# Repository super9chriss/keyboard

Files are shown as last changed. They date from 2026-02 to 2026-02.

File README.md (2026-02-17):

# custom keyboard
This is a split keyboard which can be aligned to work like a normal keyboard, it also has a removable numpad which conects to the main keyboard using pogo connectors. 
The keycaps are going to be 3d printed using these keycaps: https://www.printables.com/model/593307-low-profile-small-mx-keycaps-set/files


I wanted to make a split keyboard since my wrist hurt after typing for a long time, but im used to typing on a normal keyboard so i wanted to have this possiblity aswel,
i use a numpad for some programs so i also wanted to have that but since my desk is alway cluttered with stuff i wanted to have a keyboard which isnt too big so i made it removable.
## PCB and schematic
| **PCB Layout** | **Schematic** |
| :---: | :---: |
||
||
||
|| 
## BOM
|Description |quantity |price |link |
|---|---|---|---|
|switches |110 |25.99 + 4.72(shipping)|https://nl.aliexpress.com/item/1005010167220637.html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|
|Pico |2 |4.89 |https://nl.aliexpress.com/item/1005006839247100.html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 |
|pogo connector 5pin|2 |7.02 |https://nl.aliexpress.com/item/1005006839247100.html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 |
|diodes |110(need to order 200)|3.98 |https://nl.aliexpress.com/item/1005005574663623.html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 |
|PCB |1 |41.14 |https://cart.jlcpcb.com/shopcart/cart |
|LED |1 |0 |Self sourced |
| |total in euro: |87.74 |aliexpress coupon saves 4 euro so 83.74 |
| |in usd |100 | |

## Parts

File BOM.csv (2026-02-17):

Description | quantity | price | link
switches | 110 | 25.99 + 4.72(shipping) | https://nl.aliexpress.com/item/1005010167220637.html?mp=1
Pico | 2 | 4.89 | https://nl.aliexpress.com/item/1005006839247100.html?mp=1
pogo connector 5pin | 2 | 7.02 | https://nl.aliexpress.com/item/1005006839247100.html?mp=1
diodes | 110(need to order 200) | 3.98 | https://nl.aliexpress.com/item/1005005574663623.html?mp=1
PCB | 1 | 41.14 | https://cart.jlcpcb.com/shopcart/cart
LED | 1 | 0 | Self sourced
 | total in euro: | 87.74 | aliexpress coupon saves 4 euro so 83.74
 | in usd | 100

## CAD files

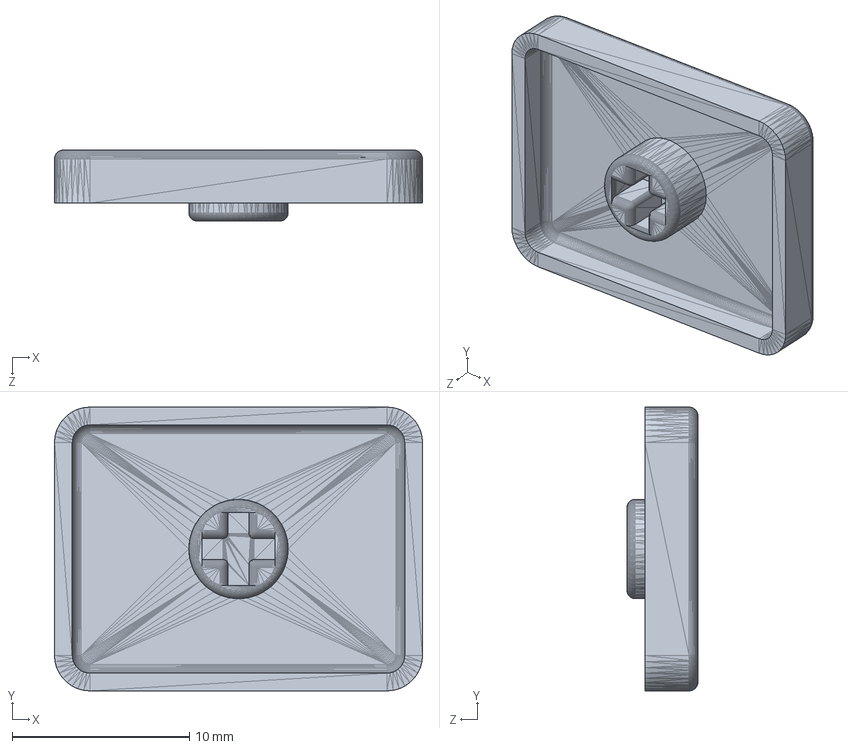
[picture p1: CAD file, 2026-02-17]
CAD/keycaps/1_25x.STEP
20.7 x 16.0 x 4.00 mm

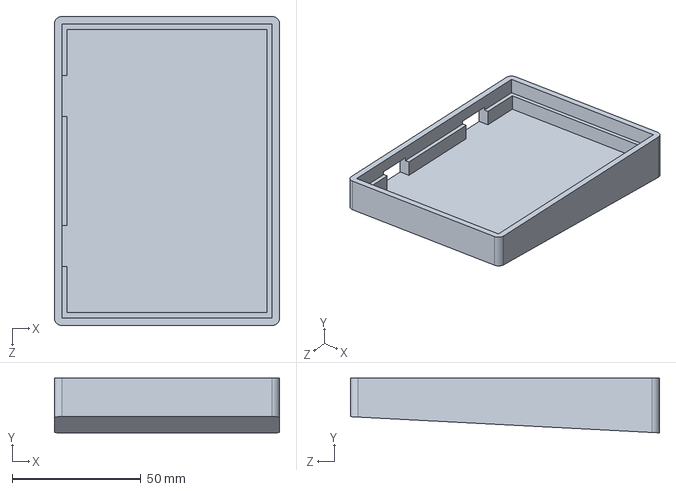
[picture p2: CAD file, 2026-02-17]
CAD/Numpad.STEP
87.7 x 21.3 x 120.2 mm

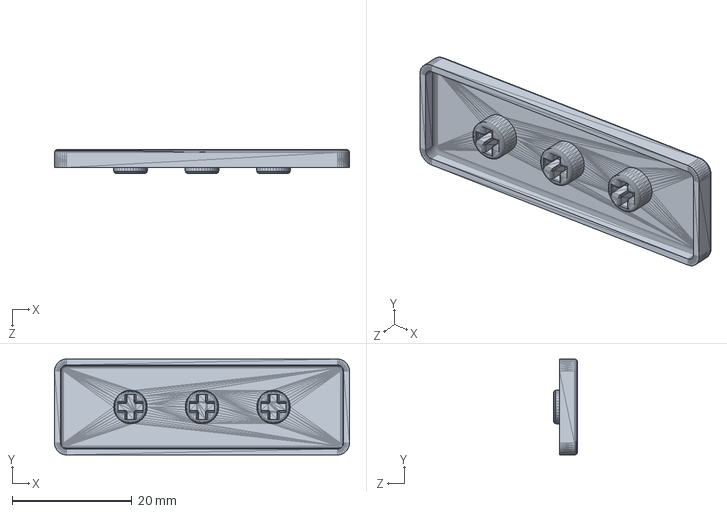
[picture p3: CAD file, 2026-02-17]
CAD/keycaps/2_75x.STEP
49.2 x 16.0 x 4.00 mm

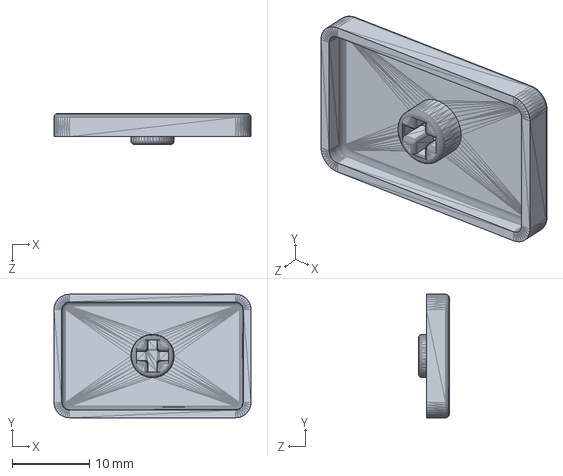
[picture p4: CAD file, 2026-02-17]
CAD/keycaps/1_5x.STEP
25.5 x 16.0 x 4.00 mm

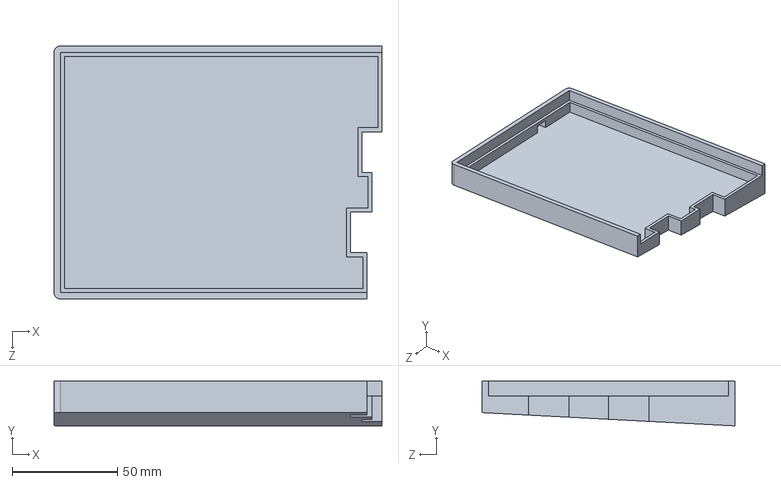
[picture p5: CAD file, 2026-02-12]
CAD/left side.SLDPRT
155.9 x 21.3 x 120.3 mm

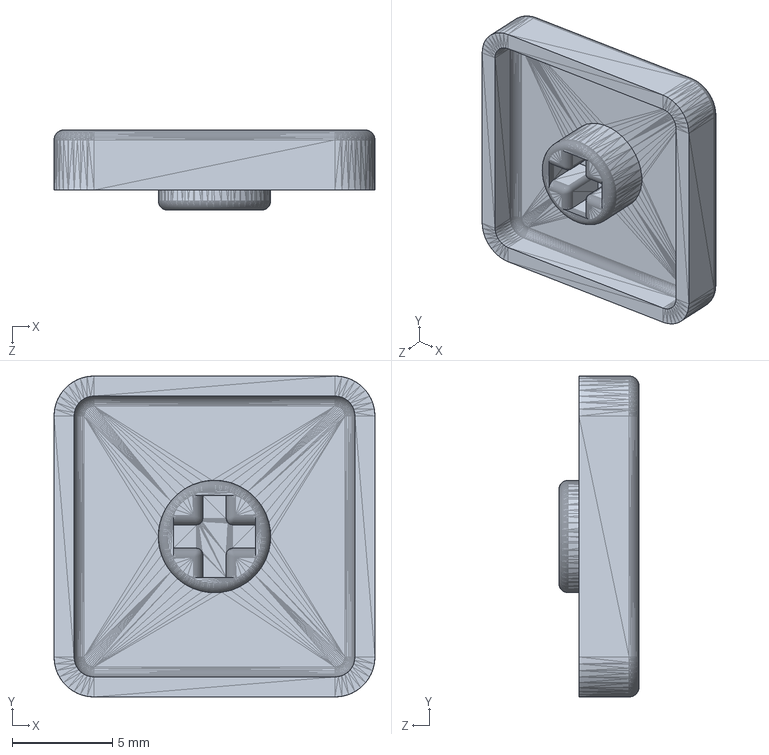
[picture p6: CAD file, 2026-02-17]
CAD/keycaps/1x.STEP
16.0 x 16.0 x 4.00 mm

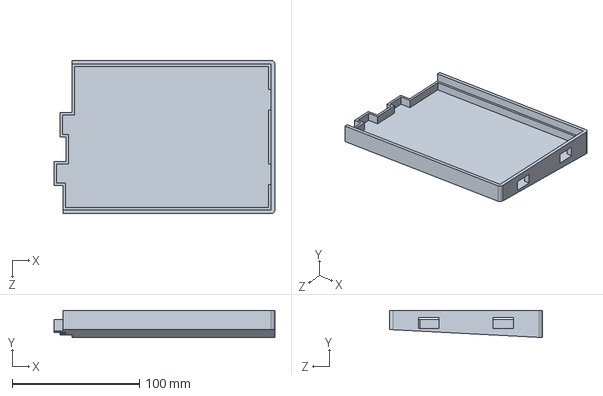
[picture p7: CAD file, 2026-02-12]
CAD/right half.SLDPRT
173.4 x 21.3 x 120.3 mm

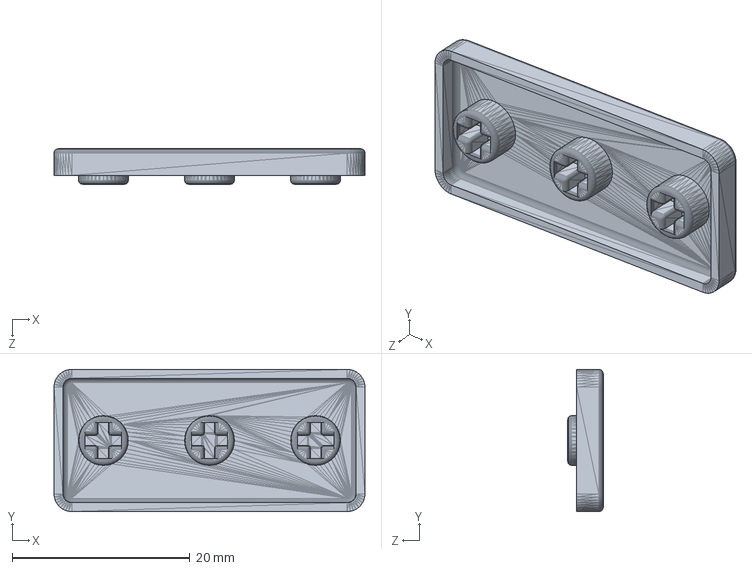
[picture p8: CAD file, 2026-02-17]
CAD/keycaps/2x.STEP
35.0 x 16.0 x 4.00 mm

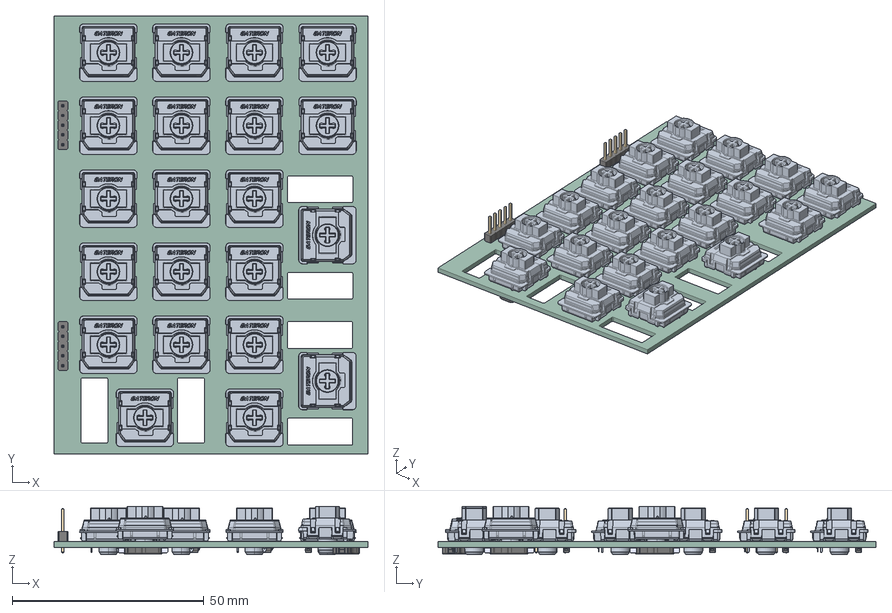
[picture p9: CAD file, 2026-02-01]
CAD/numpad PCB.step
81.8 x 114.2 x 12.6 mm
KS-33 Low Profile 2.0 KS33-20230109锛KS-33-Y31 3D寰锛 x 21
pin x 6
socket x 3
PinHeader_1x05_P2.54mm_Vertical x 2
D_SOD-123 x 21
numpad_PCB

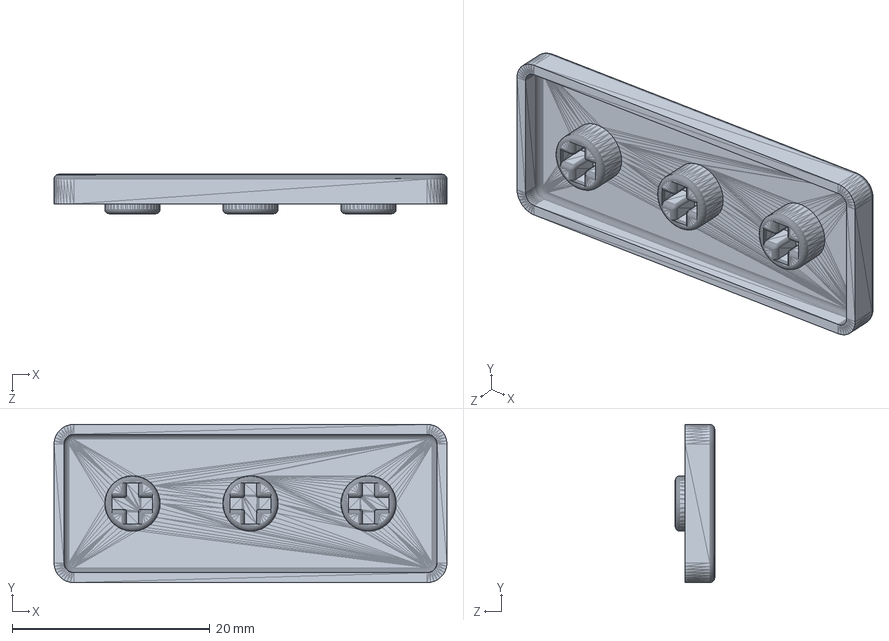
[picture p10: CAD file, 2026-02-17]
CAD/keycaps/2_25x.STEP
39.7 x 16.0 x 4.00 mm

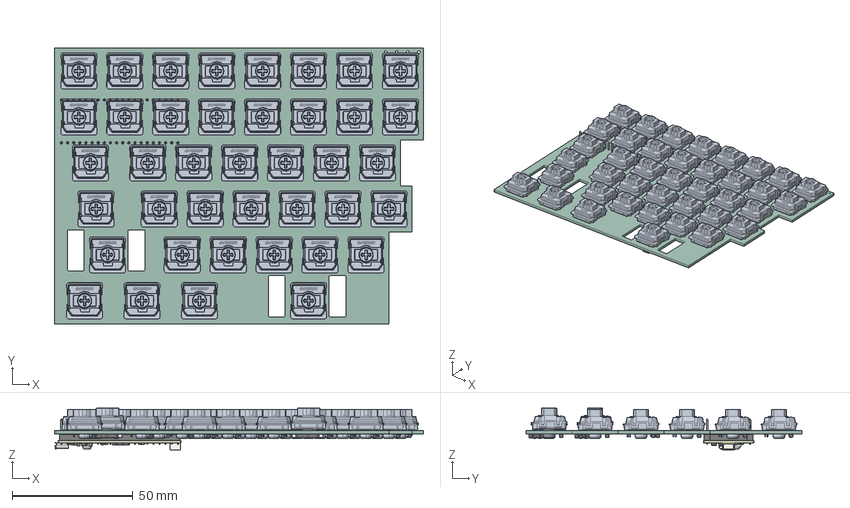
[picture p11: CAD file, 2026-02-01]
CAD/left PCB.step
153.0 x 114.3 x 17.3 mm
KS-33 Low Profile 2.0 KS33-20230109锛KS-33-Y31 3D寰锛 x 40
pin x 4
socket x 2
D_SOD-123 x 40
R_0805_2012Metric x 2
LED_SK6812MINI-E
RaspberryPi_Pico_H_Module_KiCad
RaspberryPi_Pico_Header_DIP-40_H2.54mm_KiCad
left_PCB

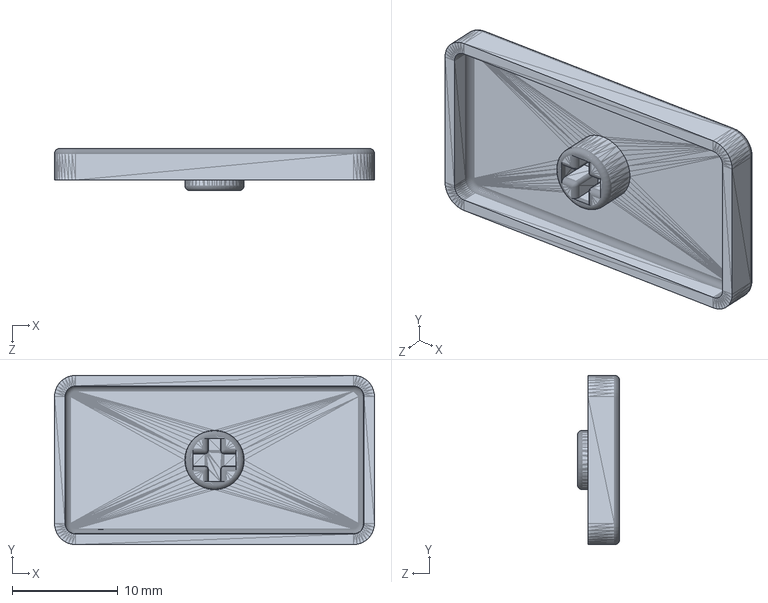
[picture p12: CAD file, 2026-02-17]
CAD/keycaps/1_75x.STEP
30.2 x 16.0 x 4.00 mm

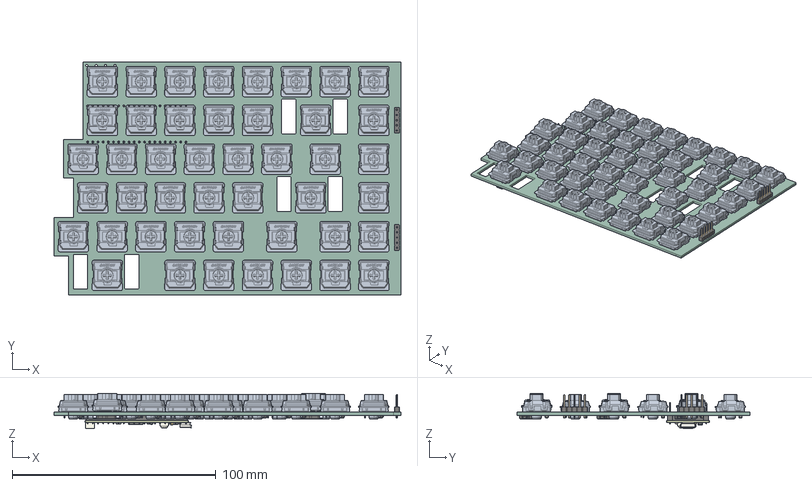
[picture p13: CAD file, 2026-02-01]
CAD/right PCB.step
170.5 x 114.3 x 17.3 mm
KS-33 Low Profile 2.0 KS33-20230109锛KS-33-Y31 3D寰锛 x 45
pin x 6
socket x 3
PinHeader_1x05_P2.54mm_Vertical x 2
D_SOD-123 x 45
RaspberryPi_Pico_H_Module_KiCad
RaspberryPi_Pico_Header_DIP-40_H2.54mm_KiCad
right_PCB

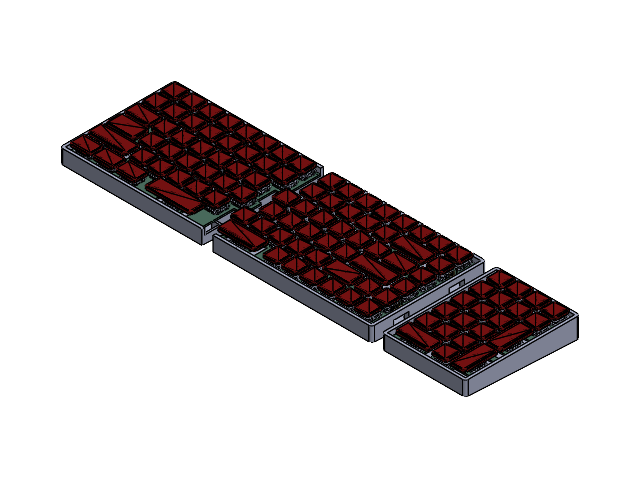
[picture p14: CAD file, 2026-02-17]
CAD/Assembely.SLDASM
left side
right half
Numpad
pin.step x 6
socket.step x 3
RaspberryPi_Pico_H_Module_KiCad.step
RaspberryPi_Pico_Header_DIP-40_H2.54mm_KiCad.step
KS-33 Low Profile 2.0 KS33-20230109______KS-33-Y31 3D____________.step x 45
PinHeader_1x05_P2.54mm_Vertical.step x 2
D_SOD-123.step x 45
right_PCB.step
pin_1.step x 4
socket_1.step x 2
RaspberryPi_Pico_H_Module_KiCad_1.step
RaspberryPi_Pico_Header_DIP-40_H2.54mm_KiCad_1.step
KS-33 Low Profile 2.0 KS33-20230109______KS-33-Y31 3D_____________1.step x 40
D_SOD-123_1.step x 40
R_0805_2012Metric.step x 2
LED_SK6812MINI-E.step
left_PCB.step
pin_2.step x 6
socket_2.step x 3
KS-33 Low Profile 2.0 KS33-20230109______KS-33-Y31 3D_____________2.step x 21
D_SOD-123_2.step x 21
numpad_PCB.step
keycap x 91
1_25x x 3
1_5x x 2
1_75x x 2
2x x 4
2_25x x 3
2_75x

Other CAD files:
CAD/right Case.STEP
CAD/left Case.STEP
CAD/Numpad.SLDPRT
CAD/keycaps/1_25x.SLDPRT
CAD/keycaps/1_5x.SLDPRT
CAD/keycaps/1_75x.SLDPRT
CAD/keycaps/1x.SLDPRT
CAD/keycaps/2_25x.SLDPRT
CAD/keycaps/2_75x.SLDPRT
CAD/keycaps/2x.SLDPRT

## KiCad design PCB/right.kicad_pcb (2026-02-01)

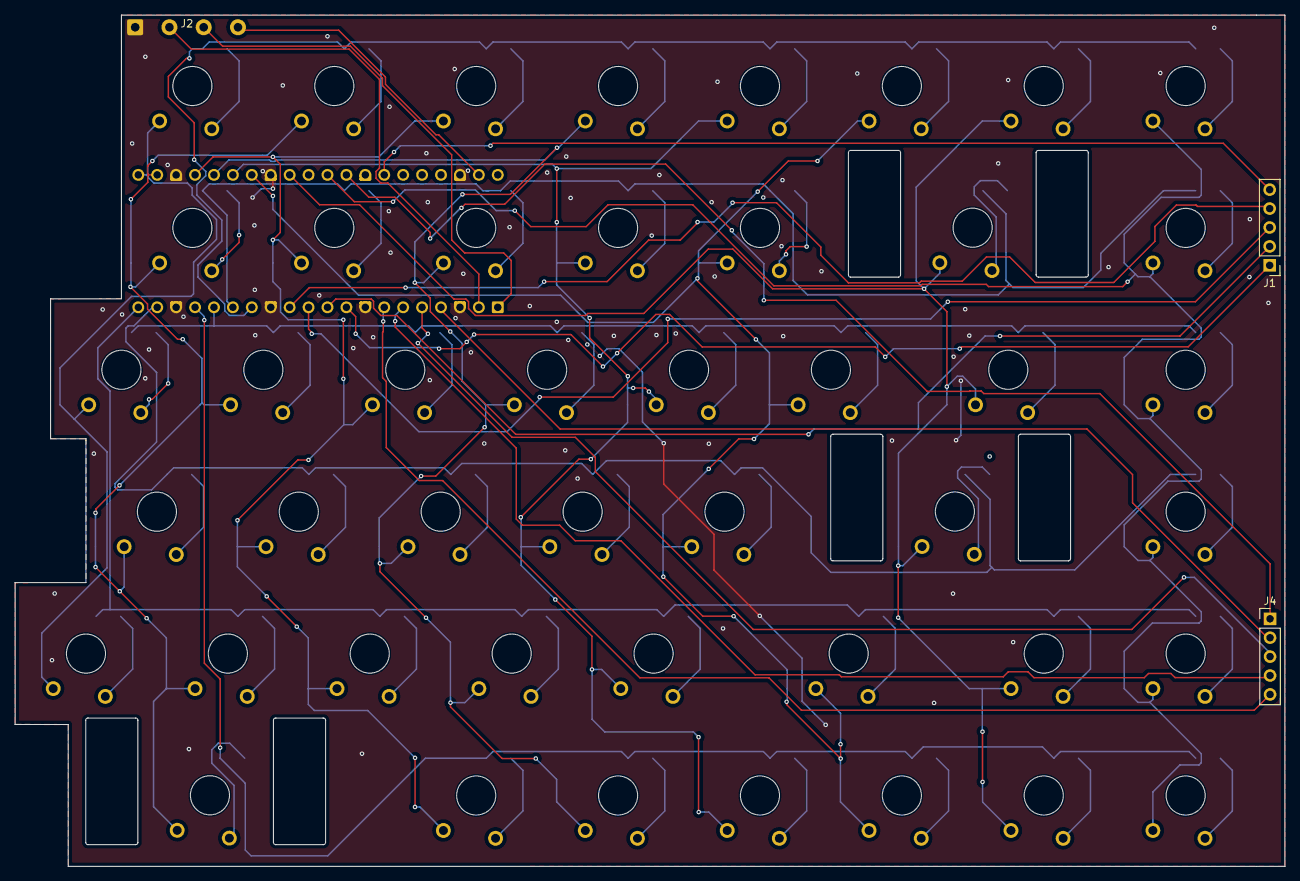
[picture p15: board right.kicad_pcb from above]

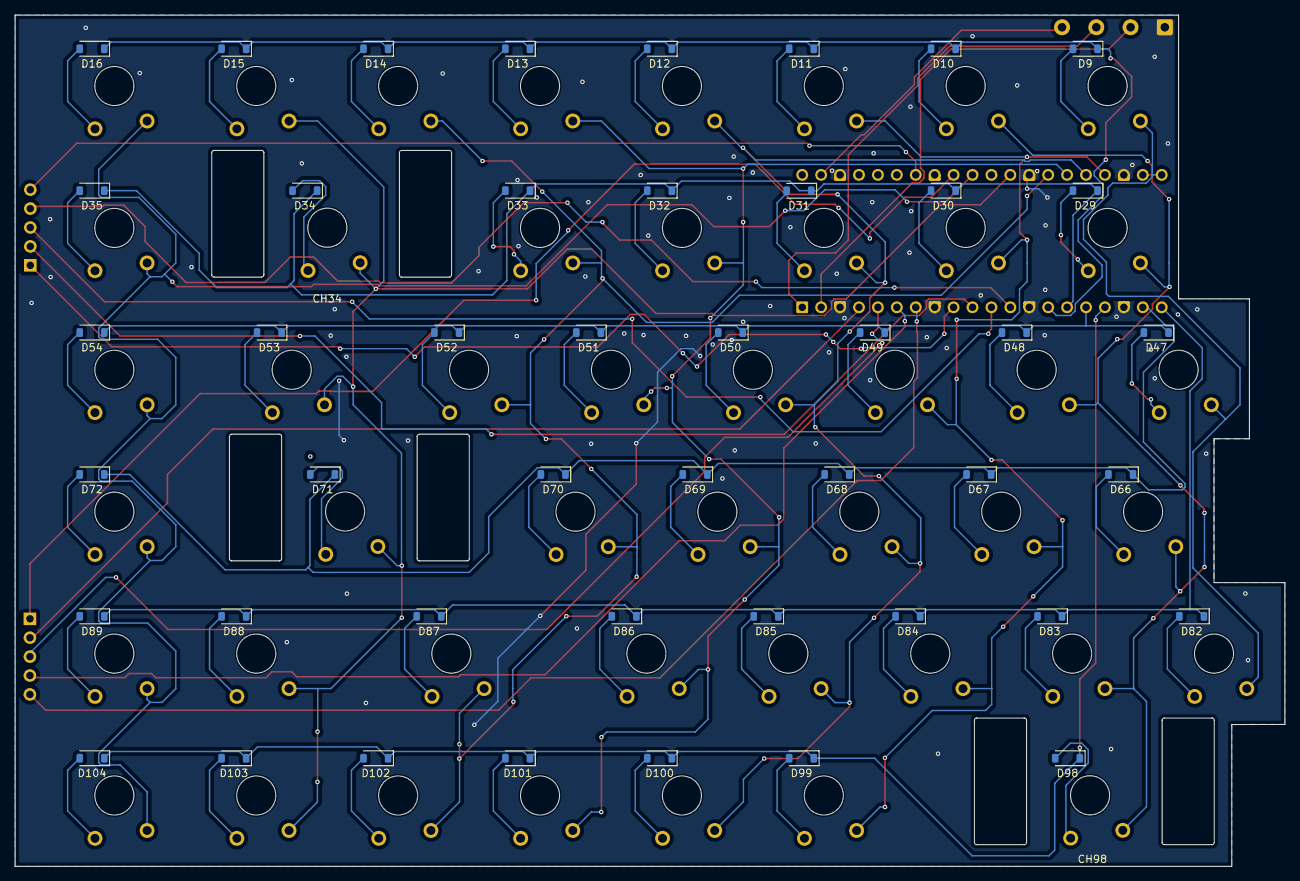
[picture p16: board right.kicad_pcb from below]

Board: 2 copper layers, 170.5 x 114.3 mm, 94 parts (46 on the bottom side), 73 nets.

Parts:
A1: RaspberryPi_Pico; RaspberryPi_Pico_Common_THT no silk only pins
CH9, CH10, CH11, CH12, CH13, CH14, CH15, CH16, CH29, CH30, CH31, CH32, CH33, CH35, CH47, CH48, CH49, CH50, CH51, CH52, CH53, CH54, CH66, CH67, CH68, CH69, CH70, CH72, CH82, CH83, CH84, CH85, CH86, CH87, CH88, CH89, CH99, CH100, CH101, CH102, CH103, CH104: KS33_SW_HS; SW_KS33_1u
CH34, CH71, CH98: KS33_SW_HS; Gateron_Low_Profile_Socket_Stabilizer_2U
D9, D10, D11, D12, D13, D14, D15, D16, D29, D30, D31, D32, D33, D34, D35, D47, D48, D49, D50, D51, D52, D53, D54, D66, D67, D68, D69, D70, D71, D72, D82, D83, D84, D85, D86, D87, D88, D89, D98, D99, D100, D101, D102, D103, D104: D; D_SOD-123
J1, J4: Conn_01x05_Socket; PinHeader_1x05_P2.54mm_Vertical
J2: Conn_01x04_Socket; SolderWire-0.5sqmm_1x04_P4.6mm_D0.9mm_OD2.1mm

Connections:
GND1: A1.3 (GND), A1.8 (GND), A1.13 (GND), A1.18 (GND), A1.23 (GND), A1.28 (GND), A1.38 (GND), J2.1
unnamed: A1.1 (GPIO0), J2.3
unnamed: A1.2 (GPIO1), J2.2
unnamed: A1.39 (VSYS), J2.4
unnamed: CH9.2, D9.2 (A)
unnamed: CH10.2, D10.2 (A)
unnamed: CH11.2, D11.2 (A)
unnamed: CH12.2, D12.2 (A)
unnamed: CH13.2, D13.2 (A)
unnamed: CH14.2, D14.2 (A)
unnamed: CH15.2, D15.2 (A)
unnamed: CH16.2, D16.2 (A)
unnamed: CH29.2, D29.2 (A)
unnamed: CH30.2, D30.2 (A)
unnamed: CH31.2, D31.2 (A)
unnamed: CH32.2, D32.2 (A)
unnamed: CH33.2, D33.2 (A)
unnamed: CH34.2, D34.2 (A)
unnamed: CH35.2, D35.2 (A)
unnamed: CH47.2, D47.2 (A)
unnamed: CH48.2, D48.2 (A)
unnamed: CH49.2, D49.2 (A)
unnamed: CH50.2, D50.2 (A)
unnamed: CH51.2, D51.2 (A)
unnamed: CH52.2, D52.2 (A)
unnamed: CH53.2, D53.2 (A)
unnamed: CH54.2, D54.2 (A)
unnamed: CH66.2, D66.2 (A)
unnamed: CH67.2, D67.2 (A)
unnamed: CH68.2, D68.2 (A)
unnamed: CH69.2, D69.2 (A)
unnamed: CH70.2, D70.2 (A)
unnamed: CH71.2, D71.2 (A)
unnamed: CH72.2, D72.2 (A)
unnamed: CH82.2, D82.2 (A)
unnamed: CH83.2, D83.2 (A)
unnamed: CH84.2, D84.2 (A)
unnamed: CH85.2, D85.2 (A)
unnamed: CH86.2, D86.2 (A)
unnamed: CH87.2, D87.2 (A)
unnamed: CH88.2, D88.2 (A)
unnamed: CH89.2, D89.2 (A)
unnamed: CH98.2, D98.2 (A)
unnamed: CH99.2, D99.2 (A)
unnamed: CH100.2, D100.2 (A)
unnamed: CH101.2, D101.2 (A)
unnamed: CH102.2, D102.2 (A)
unnamed: CH103.2, D103.2 (A)
unnamed: CH104.2, D104.2 (A)
col8: A1.21 (GPIO16), CH9.1, CH47.1, CH82.1
col9: A1.22 (GPIO17), CH10.1, CH29.1, CH48.1, CH66.1, CH83.1, CH98.1
col10: A1.24 (GPIO18), CH11.1, CH30.1, CH49.1, CH67.1, CH84.1, CH99.1
col11: A1.25 (GPIO19), CH12.1, CH31.1, CH50.1, CH68.1, CH85.1, CH100.1
col12: A1.26 (GPIO20), CH13.1, CH32.1, CH51.1, CH69.1, CH86.1, CH101.1
col13: A1.27 (GPIO21), CH14.1, CH33.1, CH52.1, CH70.1, CH87.1, CH102.1
col14: A1.29 (GPIO22), CH15.1, CH34.1, CH53.1, CH71.1, CH88.1, CH103.1
col15: A1.31 (GPIO26_ADC0), CH16.1, CH35.1, CH54.1, CH72.1, CH89.1, CH104.1
col16: A1.12 (GPIO9), J1.4
col17: A1.11 (GPIO8), J1.3
col18: A1.10 (GPIO7), J1.2
col19: A1.9 (GPIO6), J1.1
row6: A1.14 (GPIO10), D9.1 (K), D10.1 (K), D11.1 (K), D12.1 (K), D13.1 (K), D14.1 (K), D15.1 (K), D16.1 (K)
row7: A1.15 (GPIO11), D29.1 (K), D30.1 (K), D31.1 (K), D32.1 (K), D33.1 (K), D34.1 (K), D35.1 (K)
row8: A1.16 (GPIO12), D47.1 (K), D48.1 (K), D49.1 (K), D50.1 (K), D51.1 (K), D52.1 (K), D53.1 (K), D54.1 (K)
row9: A1.19 (GPIO14), D66.1 (K), D67.1 (K), D68.1 (K), D69.1 (K), D70.1 (K), D71.1 (K), D72.1 (K)
row10: A1.20 (GPIO15), D82.1 (K), D83.1 (K), D84.1 (K), D85.1 (K), D86.1 (K), D87.1 (K), D88.1 (K), D89.1 (K)
row11: A1.17 (GPIO13), D98.1 (K), D99.1 (K), D100.1 (K), D101.1 (K), D102.1 (K), D103.1 (K), D104.1 (K)
row12: A1.34 (GPIO28_ADC2), J1.5
row13: A1.32 (GPIO27_ADC1), J4.1
row14: A1.4 (GPIO2), J4.2
row15: A1.5 (GPIO3), J4.3
row16: A1.6 (GPIO4), J4.4
row17: A1.7 (GPIO5), J4.5

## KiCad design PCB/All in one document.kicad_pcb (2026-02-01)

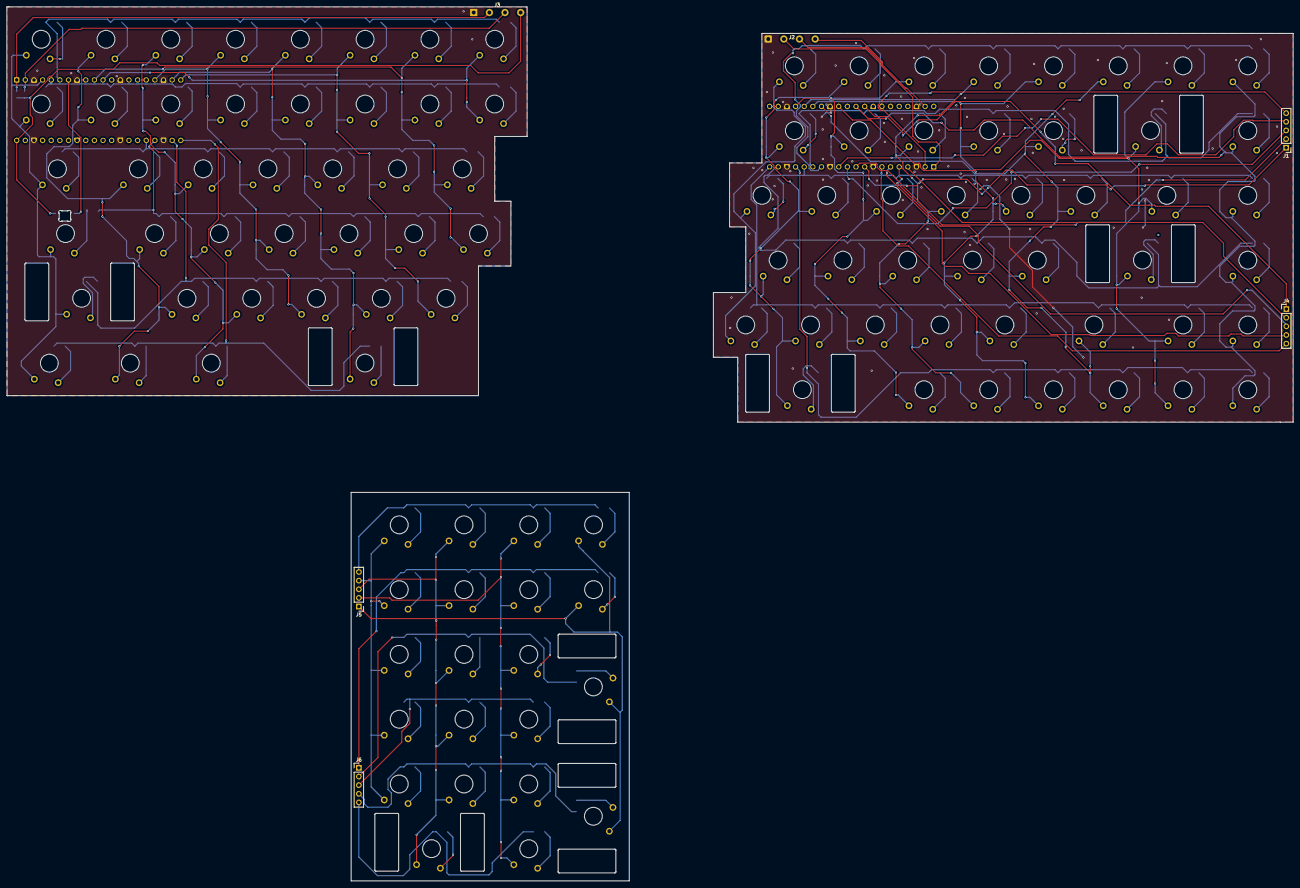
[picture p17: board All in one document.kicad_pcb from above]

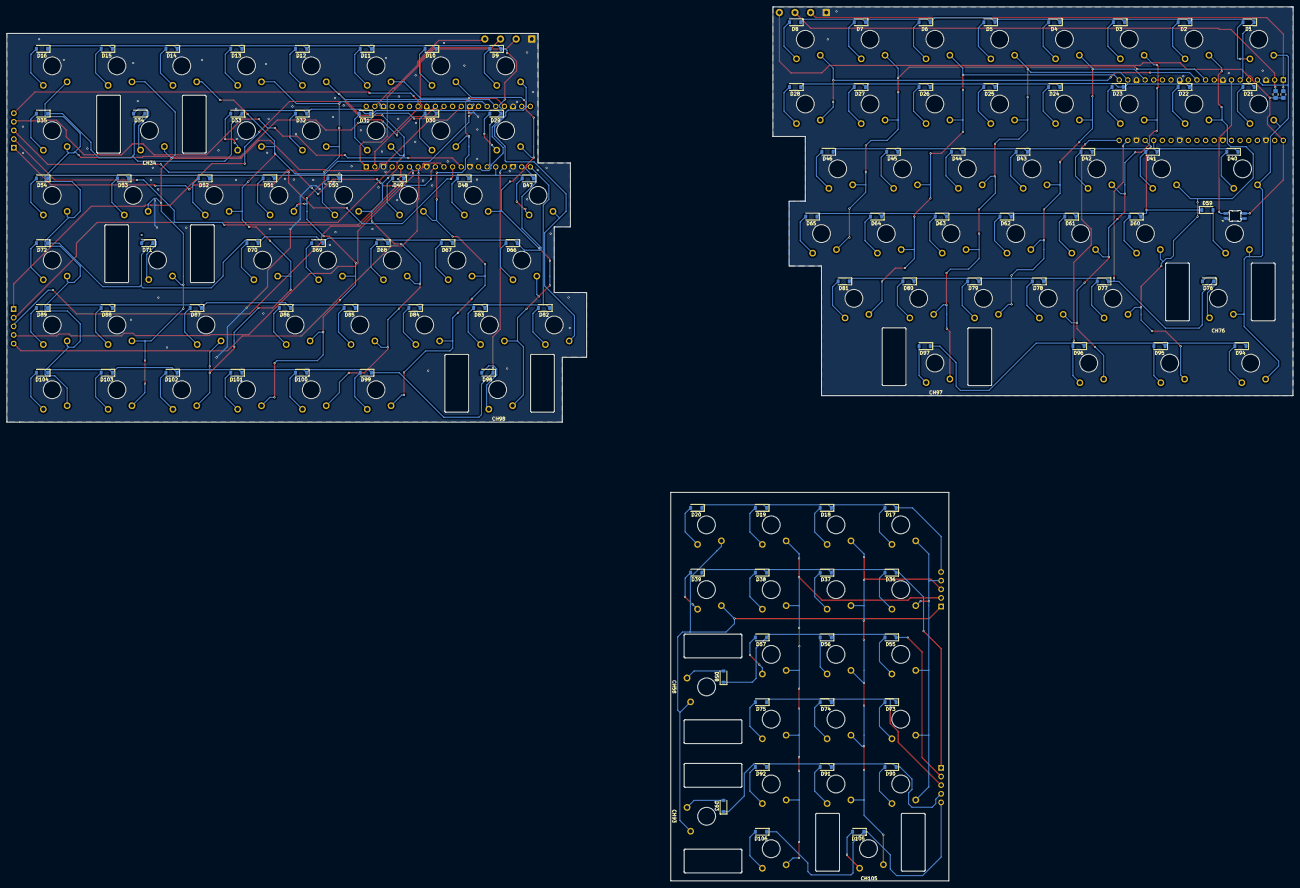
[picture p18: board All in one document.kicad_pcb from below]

Board: 2 copper layers, 378.3 x 257.0 mm, 223 parts (111 on the bottom side), 163 nets.

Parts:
A1, A2: RaspberryPi_Pico; RaspberryPi_Pico_Common_THT no silk only pins
CH1, CH2, CH3, CH4, CH5, CH6, CH7, CH8, CH9, CH10, CH11, CH12, CH13, CH14, CH15, CH16, CH17, CH18, CH19, CH20, CH21, CH22, CH23, CH24, CH25, CH26, CH27, CH28, CH29, CH30, CH31, CH32, CH33, CH35, CH36, CH37, CH38, CH39, CH40, CH41, CH42, CH43, CH44, CH45, CH46, CH47, CH48, CH49, CH50, CH51, CH52, CH53, CH54, CH55, CH56, CH57, CH59, CH60, CH61, CH62, CH63, CH64, CH65, CH66, CH67, CH68, CH69, CH70, CH72, CH73, CH74, CH75, CH77, CH78, CH79, CH80, CH81, CH82, CH83, CH84, CH85, CH86, CH87, CH88, CH89, CH90, CH91, CH92, CH94, CH95, CH96, CH99, CH100, CH101, CH102, CH103, CH104, CH106: KS33_SW_HS; SW_KS33_1u
CH34, CH58, CH71, CH76, CH93, CH97, CH98, CH105: KS33_SW_HS; Gateron_Low_Profile_Socket_Stabilizer_2U
D1, D2, D3, D4, D5, D6, D7, D8, D9, D10, D11, D12, D13, D14, D15, D16, D17, D18, D19, D20, D21, D22, D23, D24, D25, D26, D27, D28, D29, D30, D31, D32, D33, D34, D35, D36, D37, D38, D39, D40, D41, D42, D43, D44, D45, D46, D47, D48, D49, D50, D51, D52, D53, D54, D55, D56, D57, D58, D59, D60, D61, D62, D63, D64, D65, D66, D67, D68, D69, D70, D71, D72, D73, D74, D75, D76, D77, D78, D79, D80, D81, D82, D83, D84, D85, D86, D87, D88, D89, D90, D91, D92, D93, D94, D95, D96, D97, D98, D99, D100, D101, D102, D103, D104, D105, D106: D; D_SOD-123
J1, J4, J5, J6: Conn_01x05_Socket; PinHeader_1x05_P2.54mm_Vertical
J2, J3: Conn_01x04_Socket; SolderWire-0.5sqmm_1x04_P4.6mm_D0.9mm_OD2.1mm
LED1: SK6812MINI-E; LED_6028R
R1, R2: 4.7K; R_0805_2012Metric_Pad1.20x1.40mm_HandSolder

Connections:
GND1: A1.3 (GND), A1.8 (GND), A1.13 (GND), A1.18 (GND), A1.23 (GND), A1.28 (GND), A1.38 (GND), J2.1
GND2: A2.3 (GND), A2.8 (GND), A2.13 (GND), A2.18 (GND), A2.23 (GND), A2.28 (GND), A2.38 (GND), J3.1, LED1.4 (VSS)
unnamed: A1.1 (GPIO0), J2.3
unnamed: A1.2 (GPIO1), J2.2
unnamed: A1.39 (VSYS), J2.4
unnamed: A2.1 (GPIO0), J3.2, R1.2
unnamed: A2.2 (GPIO1), J3.3, R2.2
unnamed: A2.7 (GPIO5), LED1.3 (DIN)
unnamed: A2.40 (VBUS), J3.4, LED1.1 (VDD), R1.1, R2.1
unnamed: CH1.2, D1.2 (A)
unnamed: CH2.2, D2.2 (A)
unnamed: CH3.2, D3.2 (A)
unnamed: CH4.2, D4.2 (A)
unnamed: CH5.2, D5.2 (A)
unnamed: CH6.2, D6.2 (A)
unnamed: CH7.2, D7.2 (A)
unnamed: CH8.2, D8.2 (A)
unnamed: CH9.2, D9.2 (A)
unnamed: CH10.2, D10.2 (A)
unnamed: CH11.2, D11.2 (A)
unnamed: CH12.2, D12.2 (A)
unnamed: CH13.2, D13.2 (A)
unnamed: CH14.2, D14.2 (A)
unnamed: CH15.2, D15.2 (A)
unnamed: CH16.2, D16.2 (A)
unnamed: CH17.2, D17.2 (A)
unnamed: CH18.2, D18.2 (A)
unnamed: CH19.2, D19.2 (A)
unnamed: CH20.2, D20.2 (A)
unnamed: CH21.2, D21.2 (A)
unnamed: CH22.2, D22.2 (A)
unnamed: CH23.2, D23.2 (A)
unnamed: CH24.2, D24.2 (A)
unnamed: CH25.2, D25.2 (A)
unnamed: CH26.2, D26.2 (A)
unnamed: CH27.2, D27.2 (A)
unnamed: CH28.2, D28.2 (A)
unnamed: CH29.2, D29.2 (A)
unnamed: CH30.2, D30.2 (A)
unnamed: CH31.2, D31.2 (A)
unnamed: CH32.2, D32.2 (A)
unnamed: CH33.2, D33.2 (A)
unnamed: CH34.2, D34.2 (A)
unnamed: CH35.2, D35.2 (A)
unnamed: CH36.2, D36.2 (A)
unnamed: CH37.2, D37.2 (A)
unnamed: CH38.2, D38.2 (A)
unnamed: CH39.2, D39.2 (A)
unnamed: CH40.2, D40.2 (A)
unnamed: CH41.2, D41.2 (A)
unnamed: CH42.2, D42.2 (A)
unnamed: CH43.2, D43.2 (A)
unnamed: CH44.2, D44.2 (A)
unnamed: CH45.2, D45.2 (A)
unnamed: CH46.2, D46.2 (A)
unnamed: CH47.2, D47.2 (A)
unnamed: CH48.2, D48.2 (A)
unnamed: CH49.2, D49.2 (A)
unnamed: CH50.2, D50.2 (A)
unnamed: CH51.2, D51.2 (A)
unnamed: CH52.2, D52.2 (A)
unnamed: CH53.2, D53.2 (A)
unnamed: CH54.2, D54.2 (A)
unnamed: CH55.2, D55.2 (A)
unnamed: CH56.2, D56.2 (A)
unnamed: CH57.2, D57.2 (A)
unnamed: CH58.2, D58.2 (A)
unnamed: CH59.2, D59.2 (A)
unnamed: CH60.2, D60.2 (A)
unnamed: CH61.2, D61.2 (A)
unnamed: CH62.2, D62.2 (A)
unnamed: CH63.2, D63.2 (A)
unnamed: CH64.2, D64.2 (A)
unnamed: CH65.2, D65.2 (A)
unnamed: CH66.2, D66.2 (A)
unnamed: CH67.2, D67.2 (A)
unnamed: CH68.2, D68.2 (A)
unnamed: CH69.2, D69.2 (A)
unnamed: CH70.2, D70.2 (A)
unnamed: CH71.2, D71.2 (A)
unnamed: CH72.2, D72.2 (A)
unnamed: CH73.2, D73.2 (A)
unnamed: CH74.2, D74.2 (A)
unnamed: CH75.2, D75.2 (A)
unnamed: CH76.2, D76.2 (A)
unnamed: CH77.2, D77.2 (A)
unnamed: CH78.2, D78.2 (A)
unnamed: CH79.2, D79.2 (A)
unnamed: CH80.2, D80.2 (A)
unnamed: CH81.2, D81.2 (A)
unnamed: CH82.2, D82.2 (A)
unnamed: CH83.2, D83.2 (A)
unnamed: CH84.2, D84.2 (A)
unnamed: CH85.2, D85.2 (A)
unnamed: CH86.2, D86.2 (A)
unnamed: CH87.2, D87.2 (A)
unnamed: CH88.2, D88.2 (A)
unnamed: CH89.2, D89.2 (A)
unnamed: CH90.2, D90.2 (A)
unnamed: CH91.2, D91.2 (A)
unnamed: CH92.2, D92.2 (A)
unnamed: CH93.2, D93.2 (A)
unnamed: CH94.2, D94.2 (A)
unnamed: CH95.2, D95.2 (A)
unnamed: CH96.2, D96.2 (A)
unnamed: CH97.2, D97.2 (A)
unnamed: CH98.2, D98.2 (A)
unnamed: CH99.2, D99.2 (A)
unnamed: CH100.2, D100.2 (A)
unnamed: CH101.2, D101.2 (A)
unnamed: CH102.2, D102.2 (A)
unnamed: CH103.2, D103.2 (A)
unnamed: CH104.2, D104.2 (A)
unnamed: CH105.2, D105.2 (A)
unnamed: CH106.2, D106.2 (A)
col0: A2.4 (GPIO2), CH1.1, CH21.1, CH40.1, CH59.1, CH76.1, CH94.1
col1: A2.9 (GPIO6), CH2.1, CH22.1, CH41.1, CH60.1, CH77.1, CH95.1
col2: A2.16 (GPIO12), CH3.1, CH23.1, CH42.1, CH61.1, CH78.1, CH96.1
col3: A2.17 (GPIO13), CH4.1, CH24.1, CH43.1, CH62.1, CH79.1
col4: A2.19 (GPIO14), CH5.1, CH25.1, CH44.1, CH63.1, CH80.1, CH97.1
col5: A2.20 (GPIO15), CH6.1, CH26.1, CH45.1, CH64.1, CH81.1
col6: A2.10 (GPIO7), CH7.1, CH27.1, CH46.1, CH65.1
col7: A2.11 (GPIO8), CH8.1, CH28.1
col8: A1.21 (GPIO16), CH9.1, CH47.1, CH82.1
col9: A1.22 (GPIO17), CH10.1, CH29.1, CH48.1, CH66.1, CH83.1, CH98.1
col10: A1.24 (GPIO18), CH11.1, CH30.1, CH49.1, CH67.1, CH84.1, CH99.1
col11: A1.25 (GPIO19), CH12.1, CH31.1, CH50.1, CH68.1, CH85.1, CH100.1
col12: A1.26 (GPIO20), CH13.1, CH32.1, CH51.1, CH69.1, CH86.1, CH101.1
col13: A1.27 (GPIO21), CH14.1, CH33.1, CH52.1, CH70.1, CH87.1, CH102.1
col14: A1.29 (GPIO22), CH15.1, CH34.1, CH53.1, CH71.1, CH88.1, CH103.1
col15: A1.31 (GPIO26_ADC0), CH16.1, CH35.1, CH54.1, CH72.1, CH89.1, CH104.1
col16: A1.12 (GPIO9), J1.4
col16N: CH17.1, CH36.1, CH55.1, CH73.1, CH90.1, J5.4
col17: A1.11 (GPIO8), J1.3
col17N: CH18.1, CH37.1, CH56.1, CH74.1, CH91.1, CH105.1, J5.3
col18: A1.10 (GPIO7), J1.2
col18N: CH19.1, CH38.1, CH57.1, CH75.1, CH92.1, CH106.1, J5.2
col19: A1.9 (GPIO6), J1.1
col19N: CH20.1, CH39.1, CH58.1, CH93.1, J5.1
row0: A2.6 (GPIO4), D1.1 (K), D2.1 (K), D3.1 (K), D4.1 (K), D5.1 (K), D6.1 (K), D7.1 (K), D8.1 (K)
row1: A2.5 (GPIO3), D21.1 (K), D22.1 (K), D23.1 (K), D24.1 (K), D25.1 (K), D26.1 (K), D27.1 (K), D28.1 (K)
row2: A2.25 (GPIO19), D40.1 (K), D41.1 (K), D42.1 (K), D43.1 (K), D44.1 (K), D45.1 (K), D46.1 (K)
row3: A2.24 (GPIO18), D59.1 (K), D60.1 (K), D61.1 (K), D62.1 (K), D63.1 (K), D64.1 (K), D65.1 (K)
row4: A2.22 (GPIO17), D76.1 (K), D77.1 (K), D78.1 (K), D79.1 (K), D80.1 (K), D81.1 (K)
row5: A2.21 (GPIO16), D94.1 (K), D95.1 (K), D96.1 (K), D97.1 (K)
row6: A1.14 (GPIO10), D9.1 (K), D10.1 (K), D11.1 (K), D12.1 (K), D13.1 (K), D14.1 (K), D15.1 (K), D16.1 (K)
row7: A1.15 (GPIO11), D29.1 (K), D30.1 (K), D31.1 (K), D32.1 (K), D33.1 (K), D34.1 (K), D35.1 (K)
row8: A1.16 (GPIO12), D47.1 (K), D48.1 (K), D49.1 (K), D50.1 (K), D51.1 (K), D52.1 (K), D53.1 (K), D54.1 (K)
row9: A1.19 (GPIO14), D66.1 (K), D67.1 (K), D68.1 (K), D69.1 (K), D70.1 (K), D71.1 (K), D72.1 (K)
row10: A1.20 (GPIO15), D82.1 (K), D83.1 (K), D84.1 (K), D85.1 (K), D86.1 (K), D87.1 (K), D88.1 (K), D89.1 (K)
row11: A1.17 (GPIO13), D98.1 (K), D99.1 (K), D100.1 (K), D101.1 (K), D102.1 (K), D103.1 (K), D104.1 (K)
row12: A1.34 (GPIO28_ADC2), J1.5
row12N: D17.1 (K), D18.1 (K), D19.1 (K), D20.1 (K), J5.5
row13: A1.32 (GPIO27_ADC1), J4.1
row13N: D36.1 (K), D37.1 (K), D38.1 (K), D39.1 (K), J6.1
row14: A1.4 (GPIO2), J4.2
row14N: D55.1 (K), D56.1 (K), D57.1 (K), D58.1 (K), J6.2
row15: A1.5 (GPIO3), J4.3
row15N: D73.1 (K), D74.1 (K), D75.1 (K), J6.3
row16: A1.6 (GPIO4), J4.4
row16N: D90.1 (K), D91.1 (K), D92.1 (K), D93.1 (K), J6.4
row17: A1.7 (GPIO5), J4.5
row17N: D105.1 (K), D106.1 (K), J6.5

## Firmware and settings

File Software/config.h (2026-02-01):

#pragma once

/* I2C Settings for RP2040 */
#define I2C_DRIVER I2CD1
#define I2C1_SDA_PIN GP0
#define I2C1_SCL_PIN GP1

/* Split Settings */
#define USE_I2C
#define SPLIT_TRANSPORT_MIRROR
#define EE_HANDS // Gebruik EEPROM om links/rechts te bepalen

/* RGB Settings (Pico A2 GP5) */
#define RGB_DI_PIN GP5
#ifdef RGB_DI_PIN
    #define RGBLED_NUM 1 // Pas aan naar het aantal LEDS dat je hebt
    #define RGBLIGHT_HUE_STEP 8
    #define RGBLIGHT_SAT_STEP 8
    #define RGBLIGHT_VAL_STEP 8
#endif
